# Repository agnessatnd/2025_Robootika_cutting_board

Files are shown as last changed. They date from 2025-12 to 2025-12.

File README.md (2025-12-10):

# Robootika iseseisev arendusprojekt
See repositoorium on mõeldud IFI6203.DT kursuse "Robootika" üliõpilastele.  

### Mis probleemi lahendate ja miks see seade kasulik on
Meie meeskonna eesmärk on luua automaatne lõikelaud koos lõikemehhanismiga, mis suudab materjali täpselt ja korduvate tsüklite kaupa lõigata ilma käsitsi sekkumiseta. Seade aitab säästa aega, tagab korduvuse ja täpsuse ning vähendab lõikevigastuste ohtu.

### Millest seade koosneb (riistvara, kood, 3D-prinditud detailid jne)
**Põhikomponendid:**

- **Platvorm/alus:** vahtplaat, kuhu asetatakse materjal (nt banaan)  
- **Arduino Uno** (mikrokontroller)  
- **Stepper mootor + AA4988 driver**  
- **Servo mootor:** DS Servo #DS3218MG, 20 kg, 0.18 s, Digital Servo
- **Servo alus / hoidik:** 3D-prinditud, et servo oleks stabiilselt paigal  
- **Toiteallikas**— kasutame 6V
- **Lõiketera**
- **Juhtmed** -«isane-isane» ja «emane-isane»
- **Kondensaator 47 mikrofaradi **
- **Platvormi kruvid**
- **Kood on olemas src/сuttingBoard.ino**

**Rekvisiit - banaan**

### Kuidas seade töötab
Tööpõhimõte:
1. Kasutaja asetab materjali (nt banaani) seadme hoidikusse ja kinnitab selle platvormil olevate kahe kruvi abil, et see püsiks paigal vahtplaadi peal.  
2. Kasutaja lülitab seadme sisse, alustades lõikeprotsessi.  
3. Stepper mootor liigutab materjali ette ühe lõike võrra.  
4. Servo mootor  liigutab noa alla ja teeb lõike. Servo on paigaldatud 3D-prinditud alusele, mis tagab stabiilsuse ja täpsuse.  
5. Tsükkel kordub, kuni materjal on lõigatud või kasutaja lülitab seadme välja.  
6. Seade peatub automaatselt pärast tsüklite lõppu.

### Kuidas seda uuesti ehitada
1. **Kogu komponendid:** Arduino Uno, A4988 + stepper, DS3218MG servo, 6V toide, lõiketera, vahtplaat, 3D-hoidik, juhtmed, 2 kruvi.
2. **Pane mehhaanika kokku:** vahtplaadist alus + kruvid materjali kinnitamiseks; servo kinnita 3D-prinditud hoidikule; stepper joonda liikumiseks.
3. **Ühenda elektroonika:** stepper → A4988 → Arduino, servo → Arduino, ühine GND ja toide. Skeem: `hardware/wiring-diagram.png`.
4. **Laadi kood:** ava `src/cuttingBoard.ino` ja laadi see Arduino Unosse.
5. **Kasuta:** kinnita materjal(banaan) kruvidele ja lülita seade sisse – lõikamine toimub automaatselt.
   
## Kuidas seda repo't kasutada

1. Vajuta ülal paremas nurgas **Fork**.
2. Muuda `docs/PROJEKTIDOKUMENTATSIOON.md` enda projekti järgi.
3. Pane kogu kood kataloogi `src/`.
4. Pane skeemid ja riistvara info kataloogi `hardware/`.
5. Vaata oleval veebilehel ["Wiki"](https://github.com/agnessatnd/2025_Robootika_cutting_board/wiki) pilte tehtud tööst ja töövoogu kirjeldust.
7. Commiti regulaarselt (isegi pooleliolevad sammud on okei – oluline on arengulugu).

## Projekti minimaalne sisu hindamiseks

- Täidetud dokumentatsioon failis `docs/PROJEKTIDOKUMENTATSIOON.md`
- Töötav kood failis/failides `src/`
- Ühendusskeem (foto / joonis / Fritzing eksport `hardware/wiring-diagram.png`)
- Komponentide loetelu koos linkidega `hardware/komponentide-loetelu.md`

## Meeskond

- Õppeaine: IFI6203.DT Robootika  
- Autor(id): Agnessa Tund, Diana Vladõtšenko, Aleksandra Gluhhova, Alina Rohozinska
- Aasta / semester: 2025 sügis  

> NB! Ärge kustutage osi, mis on nõutud, küll aga võite lisada lisafaile (katsetused, logid, alternatiivsed skeemid jne).

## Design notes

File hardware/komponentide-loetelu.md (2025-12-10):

# Komponentide loetelu

Allpool on loetletud kõik füüsilised komponendid, millest automaatne lõikelaud koosneb. Iga komponent on valitud nii, et seadet oleks võimalik lihtsalt taastoota ja ehitada ka teistel kasutajatel.

### Mikrokontroller ja juhtimine

- **Arduino Uno**
  - Mikrokontroller, mis juhib kogu süsteemi loogikat
  - Vastutab servo ja stepper-mootori juhtimise, ajastuste ja olekute eest
  - Toide: 5V
  - https://store.arduino.cc/products/arduino-uno-rev3

### Mootorid ja liikumine

- **Stepper-mootor (nt NEMA 17)**
  - Tagab lõikelaua horisontaalse liikumise samm-sammult
  - Võimaldab väga täpset ja korduvat positsioneerimist
  - Töötab koos A4988 draiveriga

- **Stepper-mootori draiver A4988**
  - Juhib stepper-mootori samme ja suunda
  - Võimaldab reguleerida sammude kiirust ja täpsust
  - Toide: loogika 5V, mootor eraldi toiteallikast
  - https://www.pololu.com/product/1182

- **Servomootor (MS24 Digital Servo)**
  - Digitaalne servomootor
  - Vastutab noa vertikaalse liikumise eest (üles/alla)
  - Juhtimine PWM-signaaliga Arduino kaudu
  - Suurem täpsus ja jõud võrreldes tavaliste SG90 tüüpi servodega

### Lõikemehhanism

- **Nuga / lõiketera**
  - Mehaaniline lõikeelement
  - Kinnitatud servomootori hoova külge

- **Lõikelaua alus**
  - Valmistatud vahtplaadist
  - Hoiab lõigatavat materjali paigal
  - Tagab stabiilsuse lõikamise ajal

- **3D-prinditud servomootori hoidik**
  - Kasutatakse servomootori kinnitamiseks lõikemehhanismi külge
  - Parandab mehhanismi stabiilsust ja täpsust
  - Mudel on ise valmistatud ja prinditud

### Toide ja ühendused

- **Väline toiteallikas (≈ 6–12V, ≥ 2A)**
  - Toidab stepper-mootorit läbi A4988 draiveri
  - Servo ja Arduino saavad 5V toite Arduinolt

- **Breadboard (katseplaat)**
  - Kasutatakse ühenduste loomiseks ilma jootmiseta

- **Jumper-kaablid (M–M, M–F)**
  - Elektriliste ühenduste tegemiseks komponentide vahel

- **Kondensaator (47 mikrofaradi)**
  - Kasutatakse toitepinge silumiseks

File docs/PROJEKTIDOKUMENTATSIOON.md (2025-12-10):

# Projekti dokumentatsioon

## 1. Projekti eesmärk ja seadme lühikirjeldus
**Mis asi see on, mida ja miks me teeme? Millist praktilist probleemi see lahendab?**

- Meie projekti eesmärk on luua automaatne lõikelaud koos lõikemehhanismiga, mis suudab töötada korduvate tsüklite kaupa. Lõikelaud liigutab materjali või nuga täpselt etteantud sammudega edasi ning mehhanism viib noa automaatselt alla, teeb kontrollitud lõike ja tõstab selle seejärel algasendisse.
- Seadet saab kasutada näiteks kus on vaja teha täpseid ja korduvaid lõikeid ilma käsitsi tegutsemiseta. See võib olla kasulik tootmises, hobi-projektides, laboriseadmetes või lihtsalt automatiseeritud lõikamise protsessides, kus on vaja ühtlust, täpsust ja kordust.
- Peamised komponendid: servo mootor , driver, stepper mootor, arduino, nuga, lõikelaua alus. 

**Seadme kirjeldus**

Seade koosneb automaatsest lõikemehhanismist ja lõikelaua liikumissüsteemist, mis töötavad koos, et teha korduvaid ja täpseid lõikeid ilma kasutaja käsitsi sekkumiseta. Lõikemehhanismi vertikaalse liikumise eest vastutab servo mootor, mis liigutab nuga etteantud nurgani alla ja seejärel tõstab selle tagasi üles. Lõikelaua horisontaalse liikumise eest vastutab stepper mootor, mis nihutab lõigatavat materjali kindlate sammudega edasi pärast iga lõikefaasi.
Süsteem töötab tsükliliselt. Stepper liigutab lauda etteantud vahemaa. Seejärel servo aktiveerub, nuga viiakse alla ja hoitakse all täpselt määratud aja, et tagada stabiilne lõige. Kui lõige on tehtud, servo tõstab noa algasendisse ja süsteem valmistub järgmiseks sammuks. Kõik ajastused, lõikefaasid ja sammukontroll on lahendatud Arduino mikrokontrolleri abil.
Seade on ehitatud nii, et see oleks töökindel, korduv ja täpne. Lõikeprotsessis kasutatakse olekulippe ja taimeripõhist loogikat, mis tagab, et lõikamine ja liikumine toimuvad õiges järjekorras ja ilma konfliktideta. Tulemuseks on autonoomne lõikemasin, mis sobib hästi materjalide seeriatöötluseks või protsesside automatiseerimiseks, kus on vaja ühesuguseid ja korduvaid lõikeid.

---

## 2. Sisendite loetelu
**Millised on süsteemi poolt loetavad / mõõdetavad sisendid? Millega neid mõõdetakse / tuvastatakse?**

- Toide (Arduino 5V ja stepperi toiteallikas)

Allpool on kirjeldatud kõik muutujad ja väärtused, mida programm jälgib ja mille põhjal tehakse otsuseid.

#### 1. Ajasignaal lõikamise kestuse mõõtmiseks

- **Allikas:** Arduino süsteemiaeg ``millis()``

- **Mida määrab:** Kui kaua nuga on all.

- **Kasutuskoht:** Servo lõikefaasi ajastamine.

- **Seotud muutujad:** ``cutStartTime``, ``cutDuration``.

#### 2. Ajasignaal stepperi sammude intervalli jaoks

- **Allikas:** ``micros()``

- **Mida määrab:** Sammudevahelist aega mikrosekundites.

- **Kasutuskoht:** Määrab stepperi liikumise kiiruse ja ühtluse.

- **Seotud muutujad:** ``lastStepTime``, ``stepInterval``

#### 3. Oleku sisend: lõikamise olek

- **Allikas:** programmisisene väärtus ``isCutting``

- **Mida näitab:** Kas nuga on praegu all.

- **Kasutuskoht:** Servo juhtimine lõikefaasi ajal.

#### 4. Oleku sisend: lõike lõpetatus

- **Allikas:** ``cutDone``

- **Mida näitab:** Kas konkreetne lõige on lõpule viidud.

- **Kasutuskoht:** Määrab, kas süsteem läheb pausi või jätkab liikumist.

#### 5. Oleku sisend: pausirežiim

- **Allikas:** ``isPaused``

- **Mida näitab:** Kas stepper on peatatud ja toimub lõikamine.

- **Kasutuskoht:** Välistab stepperi liikumise lõikefaasis.

#### 6. Sammude loendur

- **Allikas:** ``stepsDone``

- **Mida määrab:** Mitu sammu stepper on teinud.

- **Kasutuskoht:** Kontrollib, millal tuleb aktiveerida lõige või muuta liikumissuunda.

#### 7. Sammupiirang

- **Allikas:** ``stepsLimit``

- **Mida näitab:** Maksimumsammuarvu enne liikumissuuna pööramist (edasi→tagasi)

- **Kasutuskoht:** Otsustab liikumise suunavahetuse.

#### 8. Stepperi liikumissuund

- **Allikas:** ``stepDirection``

- **Mida näitab:** Kas stepper liigub edasi või tagasi.

- **Kasutuskoht:** Suuna kontrollimine mootorile.

- **Väärtused:** 1 edasi, -1 tagasi.

#### 9. Pausitaimer

- **Allikas:** ``pauseStart``, ``pauseDuration``, ``millis()``

- **Mida määrab:** Kui kaua kestab lõikejärgne paus.

- **Kasutuskoht:** Tagab ajastatud viivituse lõikamise ja järgmise liikumise vahel.

#### 10. Lõike sammude interval

- **Allikas:** ``smallStep``

- **Mida määrab:** Iga mitme sammu järel peab toimuma lõige

- **Kasutuskoht:** Kontrollib lõikefaaside sagedust ``(stepsDone % smallStep == 0)``
  
#### 11. Servo nurga parameetrid

- **Allikas:** ``servoDownAngle (115°)``, ``servoUpAngle (0°)``

- **Mida määravad:** Noa vertikaalsed asendid

- **Kasutuskoht:** Servo positsiooni juhtimine lõikamise ajal

---

## 3. Väljundite loetelu

Süsteem juhib kahte erinevat mootorit: stepper mootorit ja servo mootorit.

- Stepper-mootor liigub edasi ja tagasi vastavalt etteantud sammude arvule → Stepper-mootor (A4988 draiver)
  - Arduino saadab A4988 draiverile STEP-signaale, millest igaüks liigutab mootorit ühe sammu võrra.
  - DIR-signaal määrab, kas mootor liigub edasi või tagasi.
  - Nii saab süsteem täpselt kontrollida mootori liikumise ulatust ja suunda, näiteks liigutada mehhanismi kindlal vahemaal edasi-tagasi.
- Servomootor liigub üles ja alla vastavalt etteantud kraadidele → Servomootor (PWM signaal Arduinost)
  - Servo saab oma asendikäsklused Arduino PWM-signaali järgi.
  - Süsteem saab määrata konkreetse nurga (nt 0°, 45°, 90°), ning servo liigub täpselt sellele asendile.

---

## 4. Nõuded loodavale seadmele
**Reeglid seadme tööks:**
**Kui stepper liigub edasi ja jõuab määratud sammude intervalli (nt iga 50 sammu), siis:**
- Stepper peatub automaatselt.
- Servo aktiveerub ja nuga viiakse alla lõikamiseks (`servoDownAngle`).
- Lõike kestus ajastatakse `cutDuration` väärtusega.

**Kui nuga on all ja lõige kestab määratud aja, siis:**
- Servo tõstab noa tagasi üles (`servoUpAngle`).
- Lõige märgitakse lõpetatuks (`cutDone = true`).
- Süsteem ootab järgmise liikumise alustamist pausiperioodi jooksul (`pauseDuration`).

**Kui paus on lõppenud ja lõige on lõpetatud, siis:**
- Stepper jätkab liikumist järgmise sammuga.
- Pausirežiim (`isPaused`) lõpetatakse.

**Kui stepper jõuab lõpp-punkti (max sammud, `stepsLimit`), siis:**
- Stepper muudab liikumissuunda tagurpidi.
- Suuna juhtimine (`dirPin`) lülitatakse tagasi.

**Kui stepper liigub tagasi ja jõuab nullpunkti (0 sammu), siis:**
- Stepper muutub suunda uuesti edasi liikuma.
- Suuna juhtimine (`dirPin`) lülitatakse ette.

**Kui kasutaja lülitab süsteemi sisse, siis:**
- Seade alustab automaatset tsüklit: stepper liigub, servo lõikab, pausid vahelduvad.

**Kui süsteem on töös, siis:**
- Kõik tegevused toimuvad tsükliliselt ja autonoomselt ilma kasutaja sekkumiseta.
- Ajastamine ja olekute jälgimine tagab, et stepper ja servo ei konfliktiks.

---

## 5. Süsteemi füüsiliste komponentide loetelu

Allpool on loetletud kõik füüsilised komponendid, millest automaatne lõikelaud koosneb. Iga komponent on valitud nii, et seadet oleks võimalik lihtsalt taastoota ja ehitada ka teistel kasutajatel.

### Mikrokontroller ja juhtimine

- **Arduino Uno**
  - Mikrokontroller, mis juhib kogu süsteemi loogikat
  - Vastutab servo ja stepper-mootori juhtimise, ajastuste ja olekute eest
  - Toide: 5V
  - https://store.arduino.cc/products/arduino-uno-rev3

### Mootorid ja liikumine

- **Stepper-mootor (nt NEMA 17)**
  - Tagab lõikelaua horisontaalse liikumise samm-sammult
  - Võimaldab väga täpset ja korduvat positsioneerimist
  - Töötab koos A4988 draiveriga

- **Stepper-mootori draiver A4988**
  - Juhib stepper-mootori samme ja suunda
  - Võimaldab reguleerida sammude kiirust ja täpsust
  - Toide: loogika 5V, mootor eraldi toiteallikast
  - https://www.pololu.com/product/1182

- **Servomootor (MS24 Digital Servo)**
  - Digitaalne servomootor
  - Vastutab noa vertikaalse liikumise eest (üles/alla)
  - Juhtimine PWM-signaaliga Arduino kaudu
  - Suurem täpsus ja jõud võrreldes tavaliste SG90 tüüpi servodega

### Lõikemehhanism

- **Nuga / lõiketera**
  - Mehaaniline lõikeelement
  - Kinnitatud servomootori hoova külge

- **Lõikelaua alus**
  - Valmistatud vahtplaadist
  - Hoiab lõigatavat materjali paigal
  - Tagab stabiilsuse lõikamise ajal

- **3D-prinditud servomootori hoidik**
  - Kasutatakse servomootori kinnitamiseks lõikemehhanismi külge
  - Parandab mehhanismi stabiilsust ja täpsust
  - Mudel on ise valmistatud ja prinditud

### Toide ja ühendused

- **Väline toiteallikas (≈ 6–12V, ≥ 2A)**
  - Toidab stepper-mootorit läbi A4988 draiveri
  - Servo ja Arduino saavad 5V toite Arduinolt

- **Breadboard (katseplaat)**
  - Kasutatakse ühenduste loomiseks ilma jootmiseta

- **Jumper-kaablid (M–M, M–F)**
  - Elektriliste ühenduste tegemiseks komponentide vahel

- **Kondensaator (47 mikrofaradi)**
  - Kasutatakse toitepinge silumiseks

## 6. Ühendusskeem



Skeemi kirjeldus:

Arduino UNO:
- D3 → A4988 STEP
- D2 → A4988 DIR
- D5 → Servo signaal
- 5V → A4988 VDD ja Servo +5V
- GND → A4988 GND, Servo GND
- GND → breadboardi -

A4988 Stepper-mootori draiver:

- VDD → Arduino 5V
- GND → Arduino GND
- STEP → Arduino D3
- DIR → Arduino D2
- 1A / 1B → Samm-mootori mähis A
- 2A / 2B → Samm-mootori mähis B
- VMOT → +V
- GND → GND
- RESET on ühendatud SLEEP piniga, et hoida draiverit ärkvel ja vältida unerežiimi.

Stepper mootor:

- Mähis A → 1A / 1B
- Mähis B → 2A / 2B

Servo:

- Signaal → Arduino D5
- +5V → Arduino 5V
- GND → Arduino GND

Väline toiteallikas (umbes 6V):

- Toiteallika +  → breadboardi +V riba
- Toiteallika –  → breadboardi GND riba

Kondensaator:

- +(pikem jalg) → breadboardi +
- – (lühem jalg) → breadboardi -

---

## 7. Süsteemi juhtiv kood
**Kirjeldus:**  
Arduino juhib automaatset lõikelauda: stepper liigutab materjali horisontaalselt ja servo tõstab/laskub nuga vertikaalselt. Seade töötab tsükliliselt, autonoomselt ja kordab lõikeprotsessi. (Tegelik töötav kood:cuttingBoard.ino)

---

#### Programmi loogika

1. **Algseadistused (`setup`)**
   - Servo ühendatakse pinnile ja tõstetakse algasendisse (**servoUpAngle**).
   - Stepperi pinnid seadistatakse väljunditeks; suund algselt ette (**dirPin = HIGH**).

2. **Põhiline tsükkel (`loop`)**
   - Kui `isPaused = true`, toimub lõikamine:
     - Servo liigub alla (**servoDownAngle**) ja hoiab aega **cutDuration**.
     - Pärast lõiget tõstetakse servo üles (**servoUpAngle**).
     - Kui pausiperiood (**pauseDuration**) möödub → stepper jätkab liikumist.
   - Kui stepperi sammude intervall möödunud:
     - Tehakse samm (**stepPin** HIGH→LOW) ja uuendatakse sammude loendur (**stepsDone**).
     - Iga **cutStepInterval** sammu järel → paus-lõikamine.
     - Kui stepper jõuab lõpp-punkti (**stepsLimit**) → suund tagurpidi.
     - Kui stepper jõuab nullpunkti → suund ette.

---

#### Märkused
- `isPaused` tagab, et stepper peatub lõike ajal.  
- `isCutting` jälgib, kas servo on all.  
- `cutDone` märgib, et lõige on lõpetatud.  
- Ajastamine toimub `millis()` ja `micros()` kaudu, et stepper ja servo ei konflikteeriks.

---
**Faili asukoht:**  
- viide failile src/сuttingBoard.ino.
---

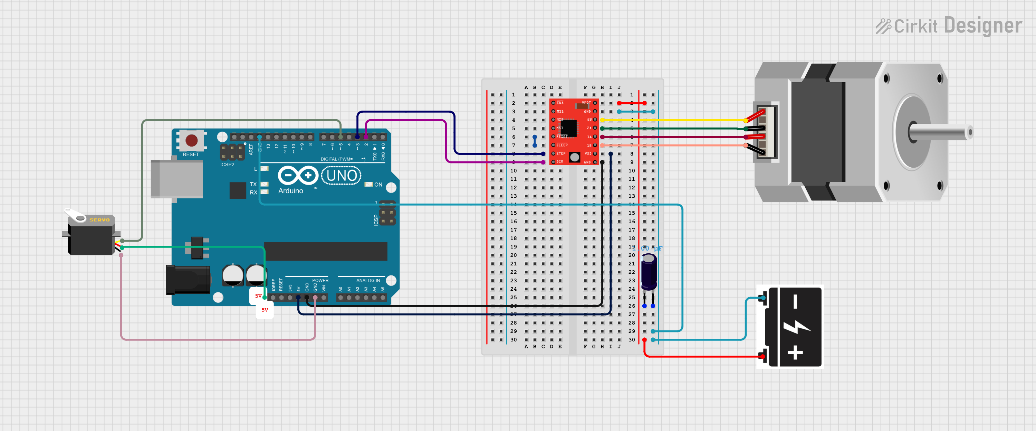
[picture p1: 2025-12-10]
hardware/ühendusskeem.png

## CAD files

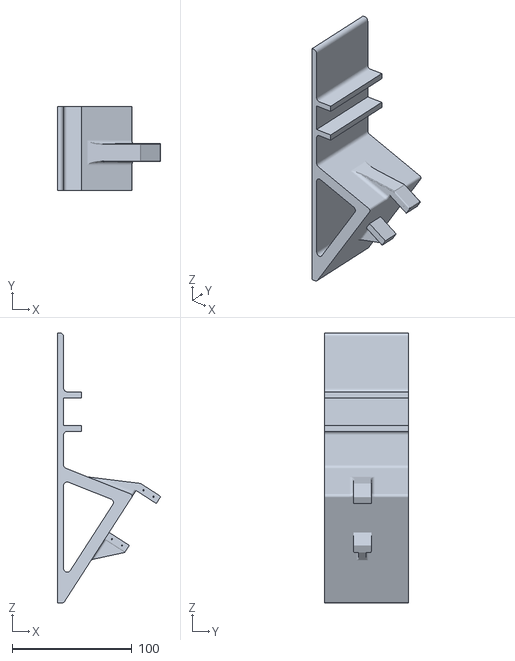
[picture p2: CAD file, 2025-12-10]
hardware/Mootori_hoidja.STL
85.6 x 70.0 x 225.0

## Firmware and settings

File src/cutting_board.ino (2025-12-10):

#include <Servo.h>

// ------------ SERVO ------------
#define SERVO_PIN 5
Servo servo;

int servoDownAngle = 115;   // nuga all
int servoUpAngle   = 50;     // nuga üleval

bool isCutting = false;
bool cutDone = false;
unsigned long cutStartTime = 0;
unsigned long cutDuration = 800;  // kui kaua nuga on all (ms)

// ------------ STEPPER ------------
const int dirPin = 2;
const int stepPin = 3;

int stepDirection = 1;      // 1 = edasi, -1 = tagasi
int smallStep = 50;         
int stepsDone = 0;          
int stepsLimit = 600;

// jätame meelde suurima tegelikult tehtud sammu arvu
int maxStepsDone = 0;

unsigned long lastStepTime = 0;
unsigned long stepInterval = 8000;

// paus
unsigned long pauseStart = 0;
unsigned long pauseDuration = 4000;
bool isPaused = false;

void setup() {
  servo.attach(SERVO_PIN);
  servo.write(servoUpAngle);

  pinMode(dirPin, OUTPUT);
  pinMode(stepPin, OUTPUT);
  digitalWrite(dirPin, HIGH);
}

void loop() {
  unsigned long nowMicros = micros();
  unsigned long nowMillis = millis();

  // ------------------------------------------------------
  // 1) PAUSIREŽIIM
  // ------------------------------------------------------
  if (isPaused) {

    // LÕIGE
    if (!cutDone) {

      if (!isCutting) {
        servo.write(servoDownAngle);
        isCutting = true;
        cutStartTime = nowMillis;
      }
      else if (nowMillis - cutStartTime >= cutDuration) {
        servo.write(servoUpAngle);
        cutDone = true;
        isCutting = false;
      }
    }

    // paus lõppeb
    if (cutDone && nowMillis - pauseStart >= pauseDuration) {
      isPaused = false;
      cutDone = false;
      isCutting = false;
    }

    return;   // stepper seisab
  }

  // ------------------------------------------------------
  // 2) TAGASISUUND
  // ------------------------------------------------------
  if (stepDirection == -1) {

    if (nowMicros - lastStepTime >= stepInterval) {
      lastStepTime = nowMicros;

      digitalWrite(stepPin, HIGH);
      delayMicroseconds(5);
      digitalWrite(stepPin, LOW);

      stepsDone--;

      // Kui jõuame tagasi algusesse → tagasi edasi suunda
      if (stepsDone <= 0) {
        stepDirection = 1;
        digitalWrite(dirPin, HIGH);

        // UUS: tsükli reset, et järgmine ring algaks nullist
        stepsDone = 0;
        maxStepsDone = 0;
      }
    }
    return;
  }

  // ------------------------------------------------------
  // 3) EDASI SUUND
  // ------------------------------------------------------
  if (nowMicros - lastStepTime >= stepInterval) {
    lastStepTime = nowMicros;

    digitalWrite(stepPin, HIGH);
    delayMicroseconds(5);
    digitalWrite(stepPin, LOW);

    stepsDone++;

    // jätame meelde reaalse maksimumi
    if (stepsDone > maxStepsDone) {
      maxStepsDone = stepsDone;
    }

    // Iga väikese distantsi järel paus sõlme jaoks
    if (stepsDone % smallStep == 0) {
      isPaused = true;
      pauseStart = nowMillis;
      cutDone = false;
      isCutting = false;
    }

    // Kui jõuti edasi liikumise piirini → tagasisuund
    if (stepsDone >= stepsLimit) {
      stepDirection = -1;
      digitalWrite(dirPin, LOW);
    }
  }
}

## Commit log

2025-10-29 Update README with project description and team info
    Added project details for an automatic cucumber cutting board, including its components and operation.
2025-10-29 Enhance README with project details
    Added details about the cucumber cutting board project, including its purpose, components, and operation.
2025-11-12 Implement servo control and update main loop
    Added servo control functionality and updated loop logic.
2025-12-09 Update operational rules for device functionality
    Added detailed rules for device operation and user interactions.
2025-12-10 add 3D model
    [Mootori_hoidja.STL]
2025-12-10 Add rebuild instructions to README
    Added a section on how to rebuild the device with components and instructions.
